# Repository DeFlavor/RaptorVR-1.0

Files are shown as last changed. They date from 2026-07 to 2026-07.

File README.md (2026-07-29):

# RaptorVR 1.0

RaptorVR 1.0 is a **prototype** SlimeVR carrier and enclosure for the **ELEGOO ESP-WROOM-32 USB-C 30-pin development board** and the **SlimeVR MuMo V1.1 ICM-45686 + QMC6309 breakout**. Its rounded outline, clear assembly zones, paired 1N5817 charge diodes, through-hole construction, and 50 mm strap chassis are inspired by the meowCarrier approach while using a larger ESP32-specific layout.

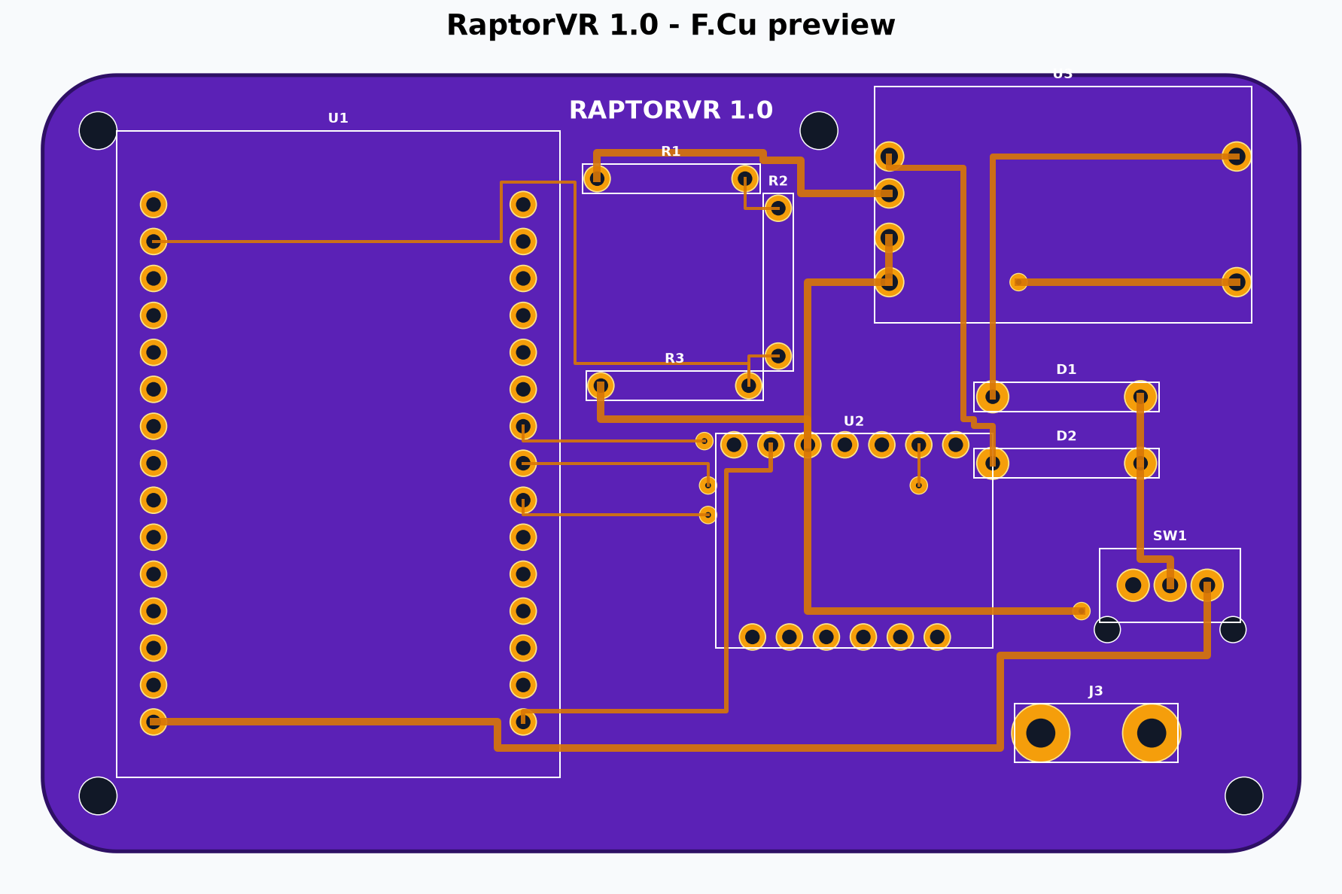
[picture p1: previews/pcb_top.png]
PCB preview


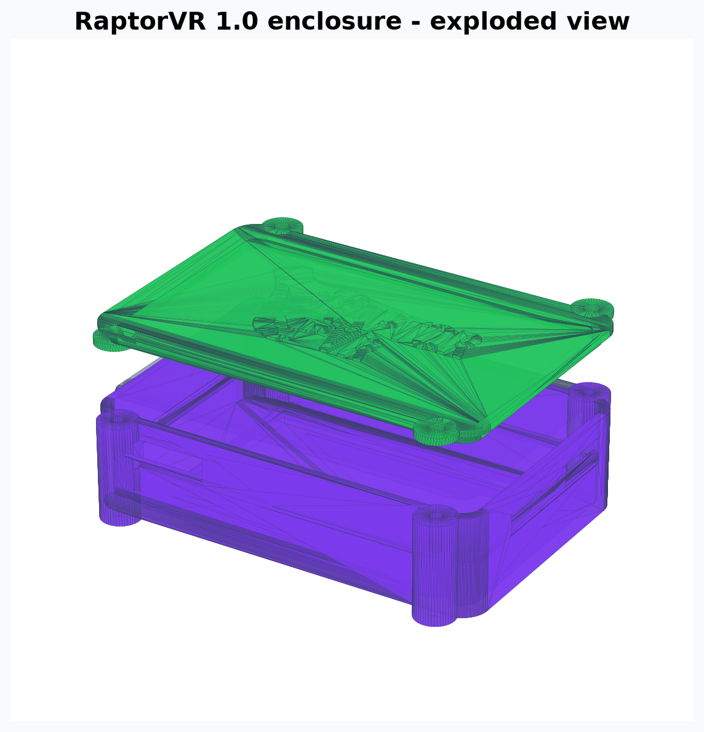
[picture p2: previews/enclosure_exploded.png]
Enclosure exploded view


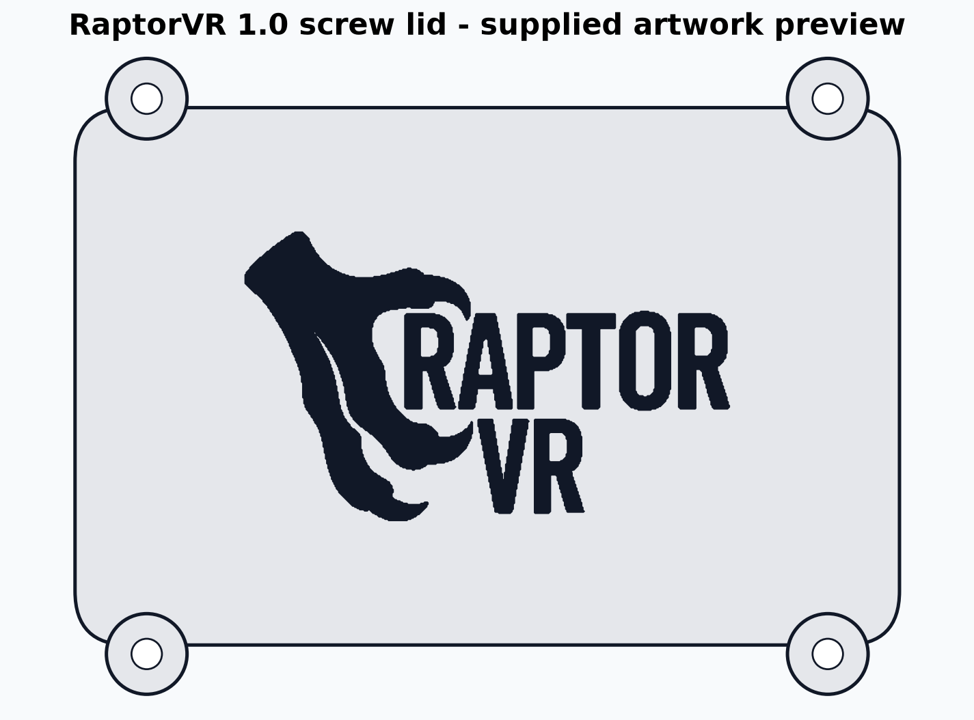
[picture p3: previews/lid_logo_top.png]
Raised logo lid preview


## Important status

This package passed automated geometry, copper-clearance, Gerber-parsing, and watertight-mesh checks. It has **not** been fabricated or electrically bench-tested. Treat revision 0.12 as a prototype and inspect it in a Gerber viewer before ordering.

## Supported parts

- ELEGOO ESP-WROOM-32 USB-C, 30 pins, two 15-pin rows on 2.54 mm pitch and 25.4 mm row spacing.
- MuMo V1.1, 18 x 13 mm, 1.2 mm thick, with both the seven-pin `J1 TOP_PINS` edge and six-pin `J2 BOTTOM_PINS` edge fitted.
- Protected TP4056 USB-C single-cell charger module, nominally 26 x 17 mm, with `IN+`, `IN-`, `B+`, `B-`, `OUT+`, and `OUT-` pads.
- Two axial 1N5817 Schottky diodes.
- 180 kOhm, 220 kOhm, and 100 kOhm 1/4 W resistors. The three-resistor divider matches the current SlimeVR `BOARD_WROOM32` defaults and feeds GPIO36/VP.
- SK12D07/SK12D07VG high-3mm SPDT slide switch.
- One protected 3.7 V, one-cell LiPo up to approximately 64 x 42 x 12 mm. The confirmed 1500 mAh battery measures 52 x 30.5 x 11 mm and fits with clearance.
- One adjustable 50 mm (2-inch) elastic or nylon body strap, 1.0-2.0 mm thick, with a side-release buckle or hook-and-loop adjustment.

## JLCPCB files

Upload [`hardware/pcb/RaptorVR_1_0_JLCPCB_Gerbers.zip`](hardware/pcb/RaptorVR_1_0_JLCPCB_Gerbers.zip) directly to JLCPCB. Recommended prototype settings:

- 2 layers, 86.36 x 53.34 mm
- 1.0 mm FR-4
- Purple solder mask for the shown style, or green for the quickest fabrication
- Lead-free HASL
- 1 oz copper
- Remove order number: specify the bottom `JLCJLCJLCJLC` location if the ordering interface supports it

The design is through-hole/module assembled. `BOM.csv` is a purchasing list; `CPL.csv` intentionally contains no SMT placement data.

## MuMo and firmware wiring

The PCB is SPI-first:

| Signal | ESP32 | MuMo |
| --- | --- | --- |
| SCLK | GPIO18 | J1.4 SCL |
| MOSI | GPIO23 | J1.5 SDA |
| MISO | GPIO19 | J1.7 SDO |
| CS | GPIO5 | J1.6 CS |
| INT1 | GPIO17 | J2.3 INT1 |
| Power | 3V3 | J1.2 3V3 |
| Ground | GND | J1.3 GND |

The same SCL/SDA wires can be used for I2C if the MuMo jumpers are configured according to its official instructions. For SPI, use a custom SlimeVR build with the pins above and ICM-45686 selected. Do not assume a generic prebuilt WROOM32 image has this exact custom SPI map.

Battery monitoring uses GPIO36/VP and these firmware values, in kOhm:

```cpp
#define PIN_BATTERY_LEVEL 36
#define BATTERY_SHIELD_RESISTANCE 180
#define BATTERY_SHIELD_R2 220
#define BATTERY_SHIELD_R1 100
```

## Enclosure

Creality Print can import the STL files in `hardware/enclosure/`:

- `RaptorVR_1_0_case_50mm_strap`: rounded chassis with ESP32 USB-C, charger USB-C, switch openings, four reinforced screw bosses, and two reinforced underside rails rotated so its 92 mm long side is vertical when worn with a 50 mm body strap.
- `RaptorVR_1_0_battery_separator_tray`: full insulating barrier between the LiPo and PCB, with PCB standoffs and a small wire slot.
- `RaptorVR_1_0_screw_lid_M3`: positively retained lid with four 3.4 mm M3 clearance holes, a 0.20 mm-per-side alignment plug, and the centered raised RaptorVR logo.
- `RaptorVR_1_0_chassis_assembled.glb` and `RaptorVR_1_0_chassis_exploded.glb`: accurate colored models for interactive orbit and zoom viewing.

The complete supplied logo image is traced directly into the lid—raptor mark, original lettering shapes, spacing, and the original `RAPTOR`/`VR` two-line arrangement. No substitute font is used. The artwork is scaled uniformly to 54 mm wide and embossed 0.8 mm above the lid for clear resin and FDM visibility. For a contrasting FDM logo, add a filament change for the final four 0.20 mm layers; a single-color print also works. For resin, angle the lid approximately 20-30 degrees and place supports on the inside face so the raised logo remains clean.

Use four **M3 x 10 mm thread-forming/self-tapping pan-head screws for plastic**. The case has 2.6 mm blind pilot holes, so the screw tips cannot reach the PCB or battery. Tighten only until the lid is seated; overtightening can strip printed threads. Do not use screws longer than 10 mm unless you first verify the remaining boss depth.

For vertical body mounting, thread one **50 mm (2-inch) elastic or nylon strap** beneath both underside rails, then add an adjustable side-release buckle or hook-and-loop closure. The rails are turned 90 degrees from the earlier layout: the strap travels across the 60 mm short side, leaving the 92 mm long side vertical on your body. The passages are 50.5 mm wide and 2.2 mm high. Round or lightly sand any sharp printed edges before installing the strap, leave enough slack for comfortable movement and circulation, and inspect the strap and rails before each use. Do not resin-print the flexible strap itself.

Starting Creality settings: 0.4 mm nozzle, 0.20 mm layers, four walls, five top/bottom layers, 35% gyroid infill, PLA+ or PETG. Print the case upright, the separator flat, and the lid with its large outer face on the build plate. If your printer runs tight, scale only the lid X/Y to 100.2% or lightly sand the alignment plug.

## Assembly safety

1. Do not attach the LiPo until every other part is soldered and inspected.
2. Verify `BAT+` and `BAT-` with a multimeter. Reversed LiPo polarity can cause fire.
3. Use only a protected one-cell LiPo and a TP4056 board that includes battery protection.
4. Confirm the TP4056 pad order against its seller diagram; visually similar boards can differ.
5. Check for shorts from `SYS_5V` to ground and from `3V3` to ground before inserting the ESP32 or MuMo.
6. The striped end of each 1N5817 goes to the PCB pad marked `K`.
7. Use USB-A-to-USB-C for inexpensive TP4056 modules unless the module explicitly supports USB-C-to-C charging.
8. Never charge an unattended or damaged LiPo, and do not wear the tracker while charging.

## Source and regeneration

- Editable PCB layout: `hardware/pcb/source/RaptorVR_1_0.kicad_pcb`
- Dimension-controlled generator: `hardware/pcb/source/generate_project.py`
- Supplied logo reference: `hardware/pcb/source/assets/RaptorVR_logo_reference.png`
- Human-readable schematic: `hardware/pcb/schematic/RaptorVR_1_0_schematic.pdf`
- Validation report: `VALIDATION.json`

Regenerate with Python 3.12 plus `numpy`, `Pillow`, `shapely`, `trimesh`, `manifold3d`, `matplotlib`, `reportlab`, and `gerbonara`.

## References and attribution

- meowCarrier by Shine Bright (MIT): https://github.com/Shine-Bright-Meow/meowCarrier
- SlimeVR tracker documentation: https://docs.slimevr.dev/diy/tracker-schematics.html
- Official MuMo V1.1 schematic: https://docs.slimevr.dev/files/mumo-schematic-1.1.pdf
- SlimeVR firmware: https://github.com/SlimeVR/SlimeVR-Tracker-ESP

The RaptorVR 1.0 scripts, PCB layout, documentation, and enclosure geometry are released under the MIT License. Third-party modules and reference projects retain their original licenses.

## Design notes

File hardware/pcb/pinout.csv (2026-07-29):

Function | ESP32 pin | MuMo pin | Notes
SPI SCLK / I2C SCL | GPIO18 | J1.4 SCL | 24 MHz SPI preferred; same wire can be I2C SCL
SPI MOSI / I2C SDA | GPIO23 | J1.5 SDA | Same wire can be I2C SDA
SPI MISO | GPIO19 | J1.7 SDO | Used in SPI mode
SPI CS | GPIO5 | J1.6 CS | Used in SPI mode
Interrupt | GPIO17 | J2.3 INT1 | Custom firmware pin
Battery ADC | GPIO36 / VP | - | 180k + 220k over 100k divider
Module power | 3V3 | J1.2 3V3 | Do not power MuMo from 5V
Ground | GND | J1.3 GND | Common ground

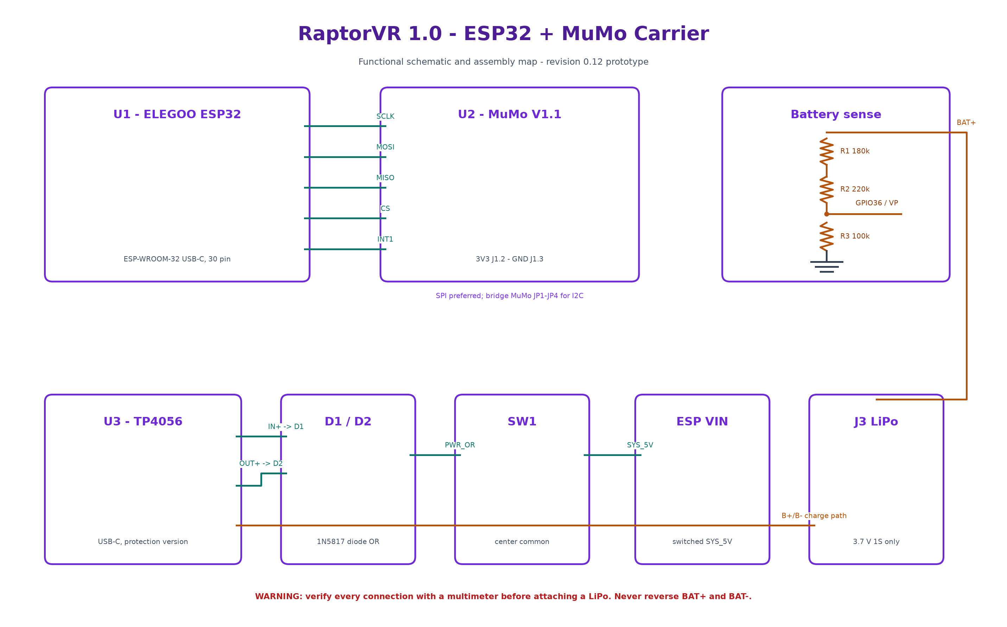
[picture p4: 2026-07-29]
hardware/pcb/schematic/RaptorVR_1_0_schematic.png

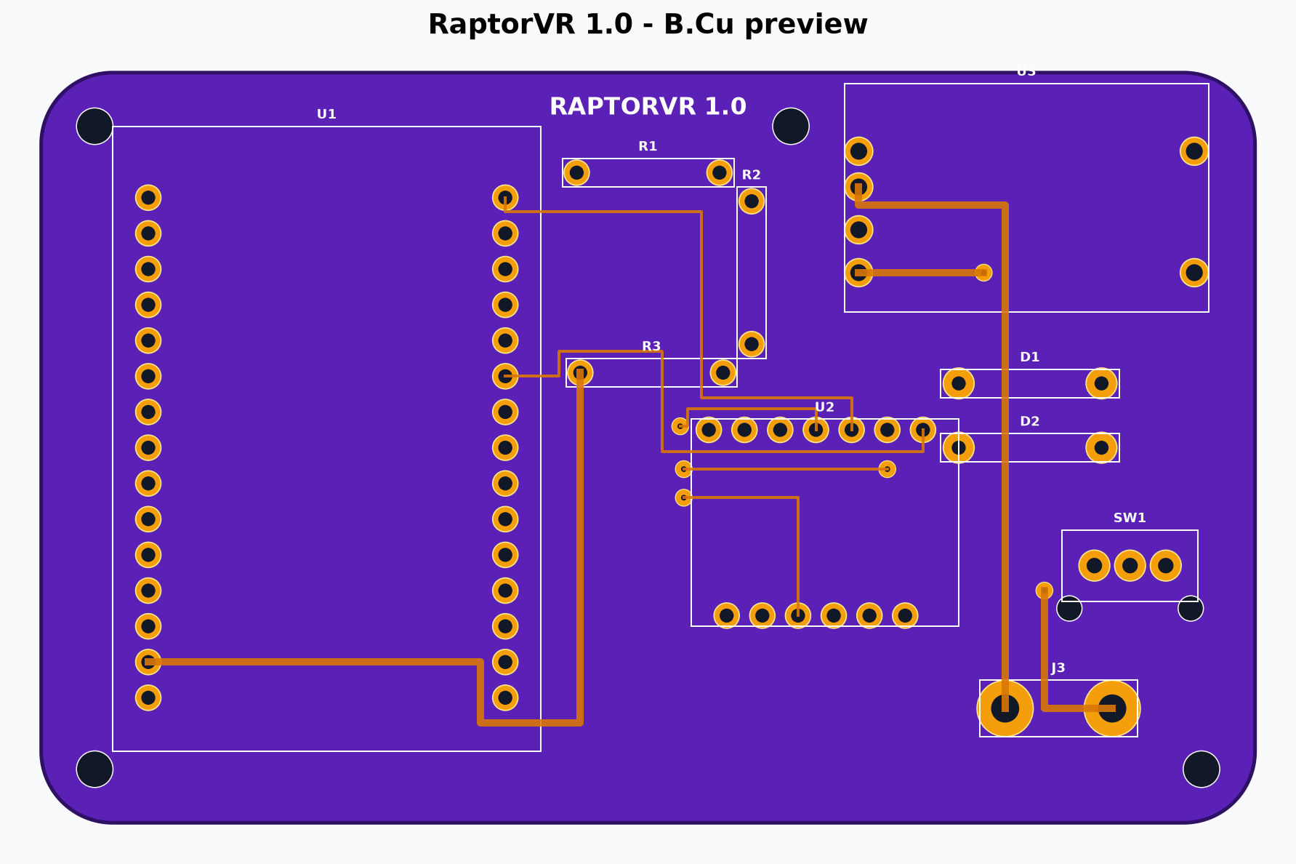
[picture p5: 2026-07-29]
previews/pcb_bottom.png

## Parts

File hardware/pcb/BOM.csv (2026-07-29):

Reference | Qty | Value / Part | Footprint / Notes | Assembly
U1 | 1 | ELEGOO ESP-WROOM-32 USB-C 30-pin | 2x15, 2.54 mm pitch, 25.4 mm row spacing | Socket or solder headers
U2 | 1 | SlimeVR MuMo V1.1 ICM-45686 + QMC6309 | 18 x 13 mm, 7+6 castellated/header pins | Fit both rows for SPI
U3 | 1 | Protected TP4056 USB-C module | Approx. 26 x 17 mm; IN+/IN-/B+/B-/OUT+/OUT- | Protection version required
D1,D2 | 2 | 1N5817 Schottky diode | DO-41 axial, 10.16 mm pitch | Band/cathode toward K
R1 | 1 | 180 kOhm 1/4 W | Axial, 10.16 mm pitch | Battery sense
R2 | 1 | 220 kOhm 1/4 W | Axial, 10.16 mm pitch | Battery divider upper
R3 | 1 | 100 kOhm 1/4 W | Axial, 10.16 mm pitch | Battery divider lower
SW1 | 1 | SK12D07/SK12D07VG high-3mm | SPDT, 2.54 mm pin pitch | Center common
J3 | 1 | 503759 3.7 V protected LiPo | Bare red/black leads to large pads | Verify polarity before soldering
Headers | 1 | 2.54 mm male/female header assortment | For ESP32, MuMo, TP4056 | Trim flush under PCB
STRAP | 1 | 50 mm (2-inch) adjustable elastic or nylon body strap with buckle | 1.0-2.0 mm thick webbing; choose a length for the intended body location | Thread beneath both rails so the chassis long side is vertical

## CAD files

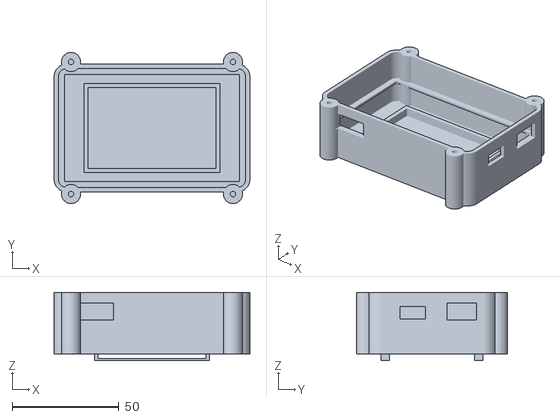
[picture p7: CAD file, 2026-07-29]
hardware/enclosure/RaptorVR_1_0_case_50mm_strap.stl
92.0 x 71.0 x 32.0

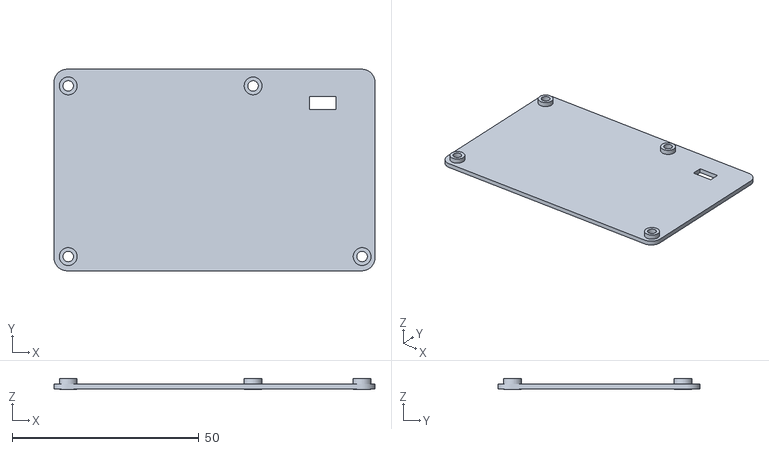
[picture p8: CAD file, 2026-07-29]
hardware/enclosure/RaptorVR_1_0_battery_separator_tray.stl
86.0 x 54.0 x 3.00

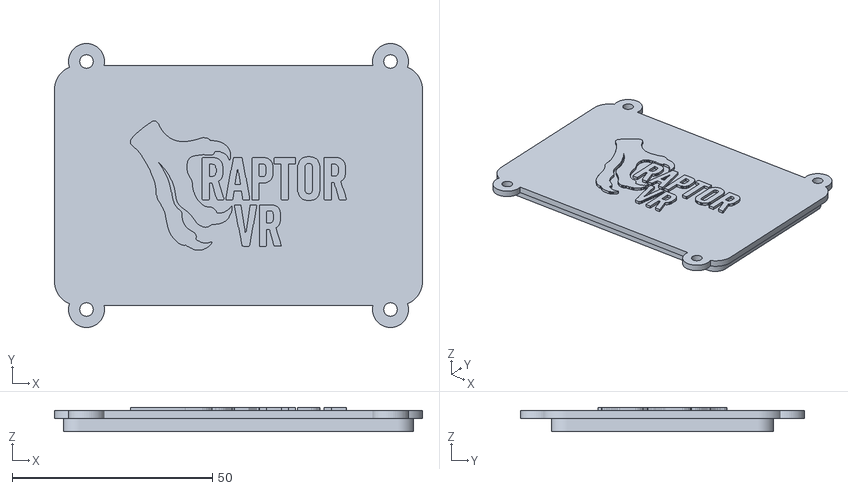
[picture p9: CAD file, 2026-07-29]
hardware/enclosure/RaptorVR_1_0_screw_lid_M3.stl
92.0 x 71.0 x 6.00

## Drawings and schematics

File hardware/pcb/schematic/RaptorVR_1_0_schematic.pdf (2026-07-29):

## U1 - ELEGOO ESP32

## U2 - MuMo V1.1

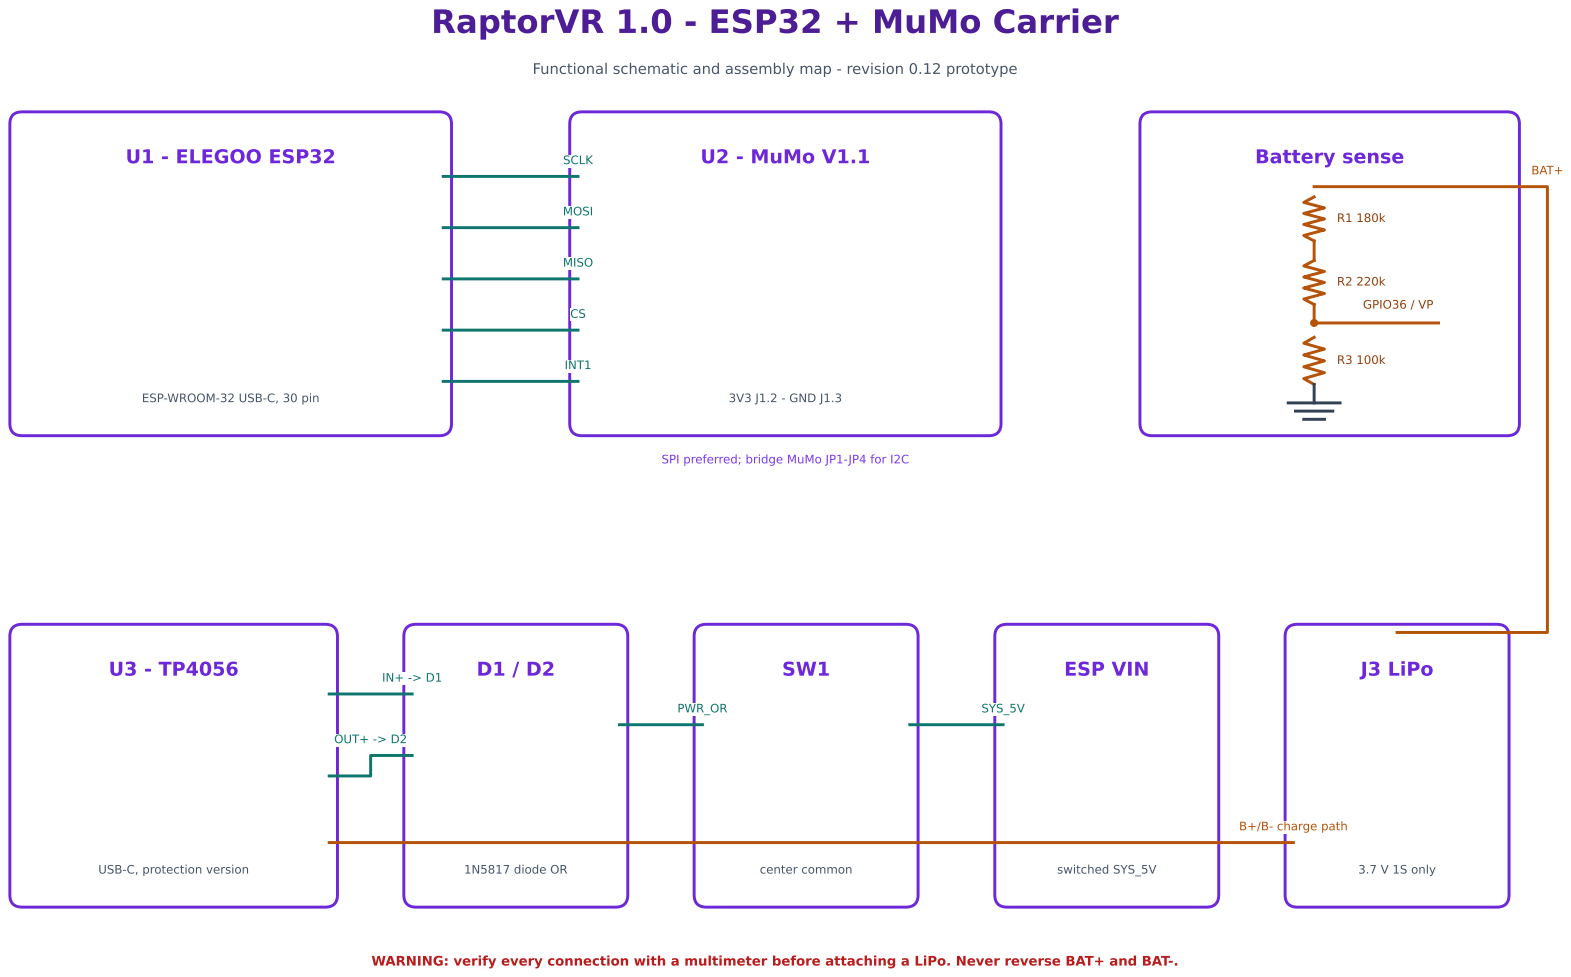
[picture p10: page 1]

Functional schematic and assembly map - revision 0.12 prototype

ESP-WROOM-32 USB-C, 30 pin

SPI preferred; bridge MuMo JP1-JP4 for I2C

WARNING: verify every connection with a multimeter before attaching a LiPo. Never reverse BAT+ and BAT-.

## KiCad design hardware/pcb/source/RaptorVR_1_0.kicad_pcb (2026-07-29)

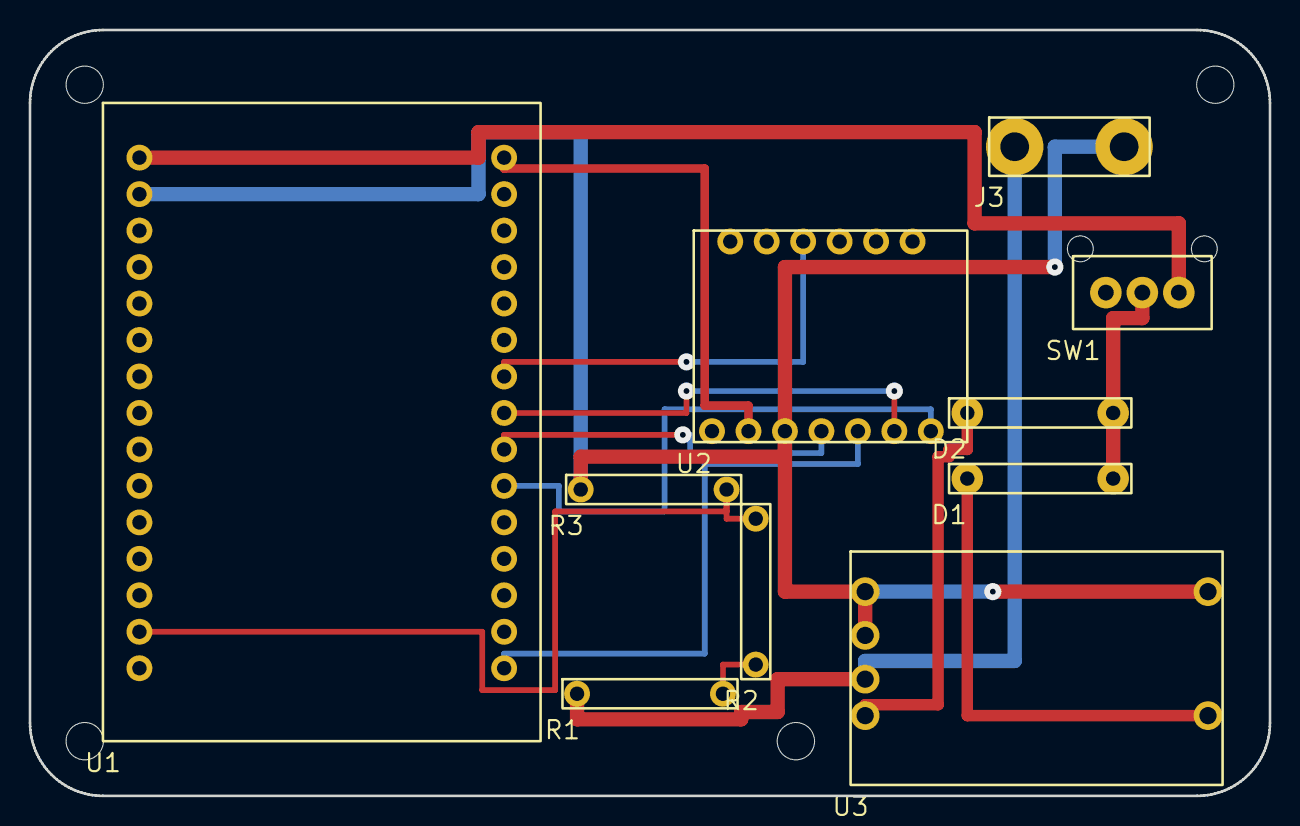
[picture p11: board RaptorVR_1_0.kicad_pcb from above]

Board: 2 copper layers, 86.4 x 53.3 mm, 10 parts (0 on the bottom side), 14 nets.

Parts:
D1: 1N5817; D1
D2: 1N5817; D2
J3: LiPo wire pads; J3
R1: 180k 1/4W; R1
R2: 220k 1/4W; R2
R3: 100k 1/4W; R3
SW1: SK12D07VG3 high-3mm; SW1
U1: ELEGOO ESP-WROOM-32 USB-C 30-pin; U1
U2: MuMo V1.1 ICM-45686 + QMC6309; U2
U3: TP4056 USB-C protected module; U3

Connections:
3V3: U1.R1, U2.2
ADC_BAT: R2.2, R3.2, U1.L14
BAT+: J3.+, R1.1, U3.5
CHG_OUT: D2.1, U3.6
CS: U1.R8, U2.6
DIV_A: R1.2, R2.1
GND: J3.-, R3.1, U1.L2, U2.3, U3.2, U3.4, U3.7
INT1: U1.R7, U2.3
MISO: U1.R10, U2.7
MOSI: U1.R15, U2.5
PWR_OR: D1.2, D2.2, SW1.2
SCLK: U1.R9, U2.4
SYS_5V: SW1.3, U1.L1
USB_IN: D1.1, U3.1

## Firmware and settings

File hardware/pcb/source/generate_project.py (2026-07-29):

from __future__ import annotations

import csv
import heapq
import io
import json
import math
import shutil
import textwrap
import zipfile
from collections import defaultdict
from dataclasses import dataclass, field
from pathlib import Path

import matplotlib

matplotlib.use("Agg")
import matplotlib.pyplot as plt
from matplotlib.patches import Circle, FancyBboxPatch, Rectangle
from matplotlib.path import Path as MplPath
from matplotlib.textpath import TextPath
from matplotlib.transforms import Affine2D
from mpl_toolkits.mplot3d.art3d import Poly3DCollection
import numpy as np
import trimesh
from PIL import Image
from shapely.affinity import scale as scale_geometry
from shapely.affinity import translate as translate_geometry
from shapely.geometry import LineString, Point, Polygon, box
from shapely.ops import unary_union


SCRIPT_PATH = Path(__file__).resolve()
SCRIPT_BYTES = SCRIPT_PATH.read_bytes()
ROOT = next(
    (
        candidate
        for candidate in SCRIPT_PATH.parents
        if (candidate / "work").is_dir() and (candidate / "outputs").is_dir()
    ),
    SCRIPT_PATH.parents[1],
)
OUT = ROOT / "outputs" / "esp32-mumo-tracker"
PCB = OUT / "hardware" / "pcb"
GERBERS = PCB / "gerbers"
SCHEMATIC = PCB / "schematic"
SOURCE = PCB / "source"
PRINTABLES = OUT / "hardware" / "enclosure"
PREVIEWS = OUT / "previews"
LOGO_ASSET = Path(__file__).resolve().parent / "assets" / "RaptorVR_logo_reference.png"
LOGO_PNG_BYTES = LOGO_ASSET.read_bytes()

GRID = 0.254  # 10 mil routing grid
BOARD_W = 86.36
BOARD_H = 53.34
BOARD_R = 5.08
CLEARANCE = 0.250
ROUTER_MARGIN = 0.18  # absorbs 10 mil grid quantization so exact geometry still clears 0.25 mm


@dataclass
class Pad:
    ref: str
    pin: str
    x: float
    y: float
    net: str
    diameter: float = 1.80
    drill: float = 1.00
    plated: bool = True
    label: str = ""

    @property
    def key(self):
        return f"{self.ref}.{self.pin}"


@dataclass
class Component:
    ref: str
    value: str
    description: str
    outline: tuple[float, float, float, float]
    pads: list[Pad] = field(default_factory=list)


@dataclass
class Track:
    net: str
    layer: str
    points: list[tuple[float, float]]
    width: float


@dataclass
class Via:
    net: str
    x: float
    y: float
    diameter: float = 1.20
    drill: float = 0.40


def mm(v: int) -> float:
    return round(v * GRID, 6)


def rounded_rect_polygon(w: float, h: float, r: float, inset: float = 0.0) -> Polygon:
    return unary_union([
        box(inset + r, inset, w - inset - r, h - inset),
        box(inset, inset + r, w - inset, h - inset - r),
        Point(inset + r, inset + r).buffer(r, resolution=32),
        Point(w - inset - r, inset + r).buffer(r, resolution=32),
        Point(w - inset - r, h - inset - r).buffer(r, resolution=32),
        Point(inset + r, h - inset - r).buffer(r, resolution=32),
    ])


def build_components() -> tuple[list[Component], list[Pad], list[Pad]]:
    components: list[Component] = []
    pads: list[Pad] = []
    npth: list[Pad] = []

    # ELEGOO ESP-WROOM-32 USB-C 30-pin board. USB-C faces the lower board edge.
    left_names = [
        ("VIN", "SYS_5V"), ("GND", "GND"), ("GPIO13", "NC"), ("GPIO12", "NC"),
        ("GPIO14", "NC"), ("GPIO27", "NC"), ("GPIO26", "NC"), ("GPIO25", "NC"),
        ("GPIO33", "NC"), ("GPIO32", "NC"), ("GPIO35", "NC"), ("GPIO34", "NC"),
        ("GPIO39", "NC"), ("GPIO36", "ADC_BAT"), ("EN", "NC"),
    ]
    right_names = [
        ("3V3", "3V3"), ("GPIO15", "NC"), ("GPIO2", "NC"), ("GPIO0", "NC"),
        ("GPIO4", "NC"), ("GPIO16", "NC"), ("GPIO17", "INT1"), ("GPIO5", "CS"),
        ("GPIO18", "SCLK"), ("GPIO19", "MISO"), ("GPIO21", "NC"), ("RX0", "NC"),
        ("TX0", "NC"), ("GPIO22", "NC"), ("GPIO23", "MOSI"),
    ]
    esp_pads = []
    for side, x, names in [("L", mm(30), left_names), ("R", mm(130), right_names)]:
        for i, (label, net) in enumerate(names):
            p = Pad("U1", f"{side}{i+1}", x, mm(35 + i * 10), net, label=label)
            esp_pads.append(p)
    components.append(Component("U1", "ELEGOO ESP-WROOM-32 USB-C 30-pin", "30-pin ESP32 development board", (mm(20), mm(20), mm(140), mm(195)), esp_pads))
    pads.extend(esp_pads)

    # MuMo V1.1 footprint: 7 top pins and 6 bottom pins, centered on an 18 x 13 mm board.
    j1_signals = [
        ("OSDO", "NC"), ("3V3", "3V3"), ("GND", "GND"), ("SCL/SCK", "SCLK"),
        ("SDA/MOSI", "MOSI"), ("CS", "CS"), ("SDO/MISO", "MISO"),
    ]
    j2_signals = [
        ("OCS", "NC"), ("CLK", "NC"), ("INT1", "INT1"), ("SCX", "NC"),
        ("SDX", "NC"), ("CLK_CTL", "NC"),
    ]
    mumo_pads = []
    for i, (label, net) in enumerate(j1_signals):
        mumo_pads.append(Pad("J1", str(i + 1), mm(187 + i * 10), mm(110), net, label=label))
    for i, (label, net) in enumerate(j2_signals):
        mumo_pads.append(Pad("J2", str(i + 1), mm(192 + i * 10), mm(58), net, label=label))
    components.append(Component("U2", "MuMo V1.1 ICM-45686 + QMC6309", "13 x 18 mm dual-row castellated breakout", (mm(182), mm(55), mm(257), mm(113)), mumo_pads))
    pads.extend(mumo_pads)

    # Common protected TP4056 USB-C module (about 26 x 17 mm). USB-C faces right.
    tp = [
        Pad("U3", "1", mm(323), mm(188), "USB_IN", 2.00, 1.20, label="IN+"),
        Pad("U3", "2", mm(323), mm(154), "GND", 2.00, 1.20, label="IN-"),
        Pad("U3", "4", mm(229), mm(166), "GND", 2.00, 1.20, label="B-"),
        Pad("U3", "5", mm(229), mm(178), "BAT+", 2.00, 1.20, label="B+"),
        Pad("U3", "6", mm(229), mm(188), "CHG_OUT", 2.00, 1.20, label="OUT+"),
        Pad("U3", "7", mm(229), mm(154), "GND", 2.00, 1.20, label="OUT-"),
    ]
    components.append(Component("U3", "TP4056 USB-C protected module", "6-pad single-cell Li-ion charger/protection module", (mm(225), mm(143), mm(327), mm(207)), tp))
    pads.extend(tp)

    # Axial 1N5817 diodes, cathodes toward the power-OR node.
    d1 = [Pad("D1", "1", mm(257), mm(123), "USB_IN", 2.20, 1.00, label="A"), Pad("D1", "2", mm(297), mm(123), "PWR_OR", 2.20, 1.00, label="K")]
    d2 = [Pad("D2", "1", mm(257), mm(105), "CHG_OUT", 2.20, 1.00, label="A"), Pad("D2", "2", mm(297), mm(105), "PWR_OR", 2.20, 1.00, label="K")]
    components.extend([
        Component("D1", "1N5817", "USB-to-load Schottky diode", (mm(252), mm(119), mm(302), mm(127)), d1),
        Component("D2", "1N5817", "battery-to-load Schottky diode", (mm(252), mm(101), mm(302), mm(109)), d2),
    ])
    pads.extend(d1 + d2)

    # Battery divider matching SlimeVR BOARD_WROOM32 defaults: 180k + 220k over 100k.
    r180 = [Pad("R1", "1", mm(150), mm(182), "BAT+", label="BAT+"), Pad("R1", "2", mm(190), mm(182), "DIV_A", label="DIV_A")]
    r220 = [Pad("R2", "1", mm(199), mm(174), "DIV_A", label="DIV_A"), Pad("R2", "2", mm(199), mm(134), "ADC_BAT", label="ADC")]
    r100 = [Pad("R3", "1", mm(151), mm(126), "GND", label="GND"), Pad("R3", "2", mm(191), mm(126), "ADC_BAT", label="ADC")]
    components.extend([
        Component("R1", "180k 1/4W", "battery sense series resistor", (mm(146), mm(178), mm(194), mm(186)), r180),
        Component("R2", "220k 1/4W", "battery sense upper divider resistor", (mm(195), mm(130), mm(203), mm(178)), r220),
        Component("R3", "100k 1/4W", "battery sense lower divider resistor", (mm(147), mm(122), mm(195), mm(130)), r100),
    ])
    pads.extend(r180 + r220 + r100)

    # SK12D07/SK12D07VG. Center common, right pad ON; left pad unused/OFF.
    sw = [
        Pad("SW1", "1", mm(295), mm(72), "NC", 2.20, 1.10, label="OFF"),
        Pad("SW1", "2", mm(305), mm(72), "PWR_OR", 2.20, 1.10, label="COM"),
        Pad("SW1", "3", mm(315), mm(72), "SYS_5V", 2.20, 1.10, label="ON"),
    ]
    components.append(Component("SW1", "SK12D07VG3 high-3mm", "SPDT slide power switch", (mm(286), mm(62), mm(324), mm(82)), sw))
    pads.extend(sw)
    npth.extend([
        Pad("SW1", "M1", mm(288), mm(60), "NPTH", 1.80, 1.80, False),
        Pad("SW1", "M2", mm(322), mm(60), "NPTH", 1.80, 1.80, False),
    ])

    # Large wire pads for the single-cell LiPo.
    bat = [
        Pad("J3", "+", mm(270), mm(32), "BAT+", 4.00, 2.00, label="BAT+"),
        Pad("J3", "-", mm(300), mm(32), "GND", 4.00, 2.00, label="BAT-")
    ]
    components.append(Component("J3", "LiPo wire pads", "3.7 V single-cell battery connection", (mm(263), mm(24), mm(307), mm(40)), bat))
    pads.extend(bat)

    # Mounting holes matching the separator tray standoffs.
    for i, (x, y) in enumerate([(mm(15), mm(15)), (mm(325), mm(15)), (mm(15), mm(195)), (mm(210), mm(195))], 1):
        npth.append(Pad("H", str(i), x, y, "NPTH", 3.00, 2.60, False))

    return components, pads, npth


def prim_edges(items: list[Pad]) -> list[tuple[Pad, Pad]]:
    if len(items) < 2:
        return []
    used = {0}
    edges = []
    while len(used) < len(items):
        best = None
        for i in used:
            for j in range(len(items)):
                if j in used:
                    continue
                d = (items[i].x - items[j].x) ** 2 + (items[i].y - items[j].y) ** 2
                if best is None or d < best[0]:
                    best = (d, i, j)
        assert best
        _, i, j = best
        edges.append((items[i], items[j]))
        used.add(j)
    return edges


class Router:
    def __init__(self, pads: list[Pad], npth: list[Pad]):
        self.pads = pads
        self.npth = npth
        self.nx = round(BOARD_W / GRID)
        self.ny = round(BOARD_H / GRID)
        self.occ = [defaultdict(set), defaultdict(set)]  # cell -> nets occupying expanded copper
        self.hard = [set(), set()]
        self.vias: list[Via] = []
        self.tracks: list[Track] = []
        self.board_safe = rounded_rect_polygon(BOARD_W, BOARD_H, BOARD_R).buffer(-0.55)
        self._mark_pad_obstacles()

    def _grid_xy(self, x: float, y: float) -> tuple[int, int]:
        return round(x / GRID), round(y / GRID)

    def _in_board(self, ix: int, iy: int) -> bool:
        if ix < 1 or iy < 1 or ix >= self.nx or iy >= self.ny:
            return False
        return self.board_safe.contains(Point(ix * GRID, iy * GRID))

    def _mark_disc(self, ix: int, iy: int, radius_mm: float, target, value):
        rr = math.ceil(radius_mm / GRID)
        for dx in range(-rr, rr + 1):
            for dy in range(-rr, rr + 1):
                if (dx * GRID) ** 2 + (dy * GRID) ** 2 <= radius_mm ** 2:
                    target[(ix + dx, iy + dy)].add(value) if isinstance(target, defaultdict) else target.add((ix + dx, iy + dy))

    def _mark_pad_obstacles(self):
        for p in self.pads:
            if p.net == "NC":
                net = p.key
            else:
                net = p.net
            ix, iy = self._grid_xy(p.x, p.y)
            for layer in range(2):
                self._mark_disc(ix, iy, p.diameter / 2 + CLEARANCE + ROUTER_MARGIN, self.occ[layer], net)
        for p in self.npth:
            ix, iy = self._grid_xy(p.x, p.y)
            for layer in range(2):
                self._mark_disc(ix, iy, p.drill / 2 + 0.60, self.hard[layer], "HARD")

    def _cell_ok(self, ix: int, iy: int, layer: int, net: str, width: float = 0.40, via: bool = False) -> bool:
        if not self._in_board(ix, iy):
            return False
        radius = 0.60 if via else width / 2
        rr = math.ceil(radius / GRID)
        layers = (0, 1) if via else (layer,)
        for ll in layers:
            for dx in range(-rr, rr + 1):
                for dy in range(-rr, rr + 1):
                    if (dx * GRID) ** 2 + (dy * GRID) ** 2 > radius ** 2:
                        continue
                    cell = (ix + dx, iy + dy)
                    if cell in self.hard[ll]:
                        return False
                    values = self.occ[ll].get(cell, set())
                    if values and any(v != net for v in values):
                        return False
        return True

    def _astar(self, a: Pad, b: Pad, net: str, width: float) -> list[tuple[int, int, int]]:
        sx, sy = self._grid_xy(a.x, a.y)
        gx, gy = self._grid_xy(b.x, b.y)
        starts = [(sx, sy, 0), (sx, sy, 1)]
        goals = {(gx, gy, 0), (gx, gy, 1)}
        pq = []
        prev = {}
        gscore = {}
        for s in starts:
            gscore[s] = 0.0
            heapq.heappush(pq, (abs(sx - gx) + abs(sy - gy), 0.0, s, None))
        visited = set()
        max_iter = self.nx * self.ny * 3
        iters = 0
        while pq and iters < max_iter:
            _, cost, state, direction = heapq.heappop(pq)
            iters += 1
            if state in visited:
                continue
            visited.add(state)
            if state in goals:
                path = [state]
                while state in prev:
                    state = prev[state]
                    path.append(state)
                return list(reversed(path))
            x, y, layer = state
            for dx, dy, ndir in ((1, 0, 0), (-1, 0, 0), (0, 1, 1), (0, -1, 1)):
                nx, ny = x + dx, y + dy
                ns = (nx, ny, layer)
                if not self._cell_ok(nx, ny, layer, net, width=width):
                    continue
                turn = 0.18 if direction is not None and ndir != direction else 0.0
                nc = cost + 1.0 + turn
                if nc < gscore.get(ns, 1e30):
                    gscore[ns] = nc
                    prev[ns] = state
                    h = abs(nx - gx) + abs(ny - gy)
                    heapq.heappush(pq, (nc + h, nc, ns, ndir))
            other = 1 - layer
            ns = (x, y, other)
            if self._cell_ok(x, y, layer, net, width=width, via=True):
                nc = cost + 14.0
                if nc < gscore.get(ns, 1e30):
                    gscore[ns] = nc
                    prev[ns] = state
                    h = abs(x - gx) + abs(y - gy)
                    heapq.heappush(pq, (nc + h, nc, ns, direction))
        raise RuntimeError(f"Autorouter failed for {net}: {a.key} -> {b.key}")

    def _commit(self, path: list[tuple[int, int, int]], net: str, width: float):
        # Mark copper occupancy with clearance.
        route_radius = width / 2 + CLEARANCE + ROUTER_MARGIN
        rr = math.ceil(route_radius / GRID)
        for x, y, layer in path:
            for dx in range(-rr, rr + 1):
                for dy in range(-rr, rr + 1):
                    if (dx * GRID) ** 2 + (dy * GRID) ** 2 <= route_radius ** 2:
                        self.occ[layer][(x + dx, y + dy)].add(net)

        # Split by layer and compress collinear grid walks.
        chunks = []
        chunk = [path[0]]
        for item in path[1:]:
            if item[2] != chunk[-1][2]:
                chunks.append(chunk)
                chunk = [item]
            else:
                chunk.append(item)
        chunks.append(chunk)
        for ch in chunks:
            if len(ch) < 2:
                continue
            pts = [(ch[0][0], ch[0][1])]
            last_dir = None
            for i in range(1, len(ch)):
                d = (ch[i][0] - ch[i - 1][0], ch[i][1] - ch[i - 1][1])
                if last_dir is not None and d != last_dir:
                    pts.append((ch[i - 1][0], ch[i - 1][1]))
                last_dir = d
            pts.append((ch[-1][0], ch[-1][1]))
            mmpts = [(mm(x), mm(y)) for x, y in pts]
            self.tracks.append(Track(net, "F.Cu" if ch[0][2] == 0 else "B.Cu", mmpts, width))

        for i in range(1, len(path)):
            if path[i][2] != path[i - 1][2]:
                x, y, _ = path[i]
                if not any(abs(v.x - mm(x)) < 1e-6 and abs(v.y - mm(y)) < 1e-6 and v.net == net for v in self.vias):
                    via = Via(net, mm(x), mm(y))
                    self.vias.append(via)
                    for ll in (0, 1):
                        self._mark_disc(x, y, via.diameter / 2 + CLEARANCE + ROUTER_MARGIN, self.occ[ll], net)

    def route_all(self):
        net_pads: dict[str, list[Pad]] = defaultdict(list)
        for p in self.pads:
            if p.net not in ("NC", "NPTH"):
                net_pads[p.net].append(p)

        order = [
            "USB_IN", "CHG_OUT", "PWR_OR", "SYS_5V", "BAT+", "3V3", "GND",
            "SCLK", "MOSI", "MISO", "CS", "INT1", "ADC_BAT", "DIV_A",
        ]
        widths = defaultdict(lambda: 0.40, {"USB_IN": 0.80, "CHG_OUT": 0.80, "PWR_OR": 1.00, "SYS_5V": 1.00, "BAT+": 1.00, "GND": 1.00, "3V3": 0.60})
        for net in order:
            items = net_pads[net]
            for a, b in prim_edges(items):
                path = self._astar(a, b, net, widths[net])
                self._commit(path, net, widths[net])
        return self.tracks, self.vias


def gerber_coord(v: float) -> str:
    return f"{round(v * 1_000_000):010d}"


def gerber_header(name: str) -> list[str]:
    return [
        f"G04 {name}*", "%FSLAX46Y46*%", "%MOMM*%", "%IPPOS*%", "%LPD*%",
        "%ADD10C,0.400*%", "%ADD11C,0.600*%", "%ADD12C,0.800*%", "%ADD13C,1.000*%",
        "%ADD14C,1.200*%", "%ADD15C,1.800*%", "%ADD16C,2.200*%", "%ADD17C,2.400*%",
        "%ADD18C,4.000*%", "%ADD19C,0.180*%", "G01*",
    ]


def flash(lines, x, y, dcode):
    lines.append(f"D{dcode}*")
    lines.append(f"X{gerber_coord(x)}Y{gerber_coord(y)}D03*")


def draw_polyline(lines, points, dcode):
    if len(points) < 2:
        return
    lines.append(f"D{dcode}*")
    x, y = points[0]
    lines.append(f"X{gerber_coord(x)}Y{gerber_coord(y)}D02*")
    for x, y in points[1:]:
        lines.append(f"X{gerber_coord(x)}Y{gerber_coord(y)}D01*")


def write_region(lines, poly: list[tuple[float, float]]):
    if len(poly) < 3:
        return
    lines.append("G36*")
    lines.append(f"X{gerber_coord(poly[0][0])}Y{gerber_coord(poly[0][1])}D02*")
    for x, y in poly[1:]:
        lines.append(f"X{gerber_coord(x)}Y{gerber_coord(y)}D01*")
    lines.append(f"X{gerber_coord(poly[0][0])}Y{gerber_coord(poly[0][1])}D01*")
    lines.append("G37*")


def text_polygons(text: str, x: float, y: float, size: float, angle: float = 0.0, center: bool = False):
    path = TextPath((0, 0), text, size=size, prop={"family": "DejaVu Sans", "weight": "bold"})
    polys = path.to_polygons()
    if not polys:
        return []
    allpts = np.vstack(polys)
    minx, miny = allpts.min(axis=0)
    maxx, maxy = allpts.max(axis=0)
    tx = -(minx + maxx) / 2 if center else -minx
    ty = -(miny + maxy) / 2 if center else -miny
    transform = Affine2D().translate(tx, ty).rotate_deg(angle).translate(x, y)
    return [transform.transform(p).tolist() for p in polys]
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

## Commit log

2026-07-29 Initial PurrTrack32 prototype design
    [BOM.csv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]
2026-07-29 Replace snap lid with four-screw M3 enclosure
    [PurrTrack32_case_50mm_strap.stl, PurrTrack32_screw_lid_M3.stl, PurrTrack32_snap_lid.stl]
2026-07-29 Rename project to RaptorVR 1.0
    [RaptorVR_1_0-B_Cu.gbl, RaptorVR_1_0-B_Mask.gbs, RaptorVR_1_0-B_Silkscreen.gbo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]
2026-07-29 Resize enclosure for 1500 mAh battery
    [RaptorVR_1_0_case_50mm_strap.stl]
2026-07-29 Add raised RaptorVR logo to screw lid
    [RaptorVR_1_0_screw_lid_M3.stl]
2026-07-29 Position lid lettering inside raptor grip
    [RaptorVR_1_0_screw_lid_M3.stl]
2026-07-29 Reduce lid logo lettering size
    [RaptorVR_1_0_screw_lid_M3.stl]
2026-07-29 Set RaptorVR lid text on one line
    [RaptorVR_1_0_screw_lid_M3.stl]
2026-07-29 Remove space from RaptorVR lid text
    [RaptorVR_1_0_screw_lid_M3.stl]
2026-07-29 Increase lid logo relief for resin printing
    [RaptorVR_1_0_screw_lid_M3.stl]
2026-07-29 Trace exact supplied logo artwork onto lid
    [RaptorVR_1_0_screw_lid_M3.stl]
2026-07-29 Add interactive assembled and exploded chassis models
2026-07-29 Fix interactive chassis GLB scale and materials
    [generate_project.py]
2026-07-29 Document 50 mm body strap mounting
    [BOM.csv]
2026-07-29 Rotate strap rails for vertical wear
    [BOM.csv, RaptorVR_1_0_case_50mm_strap.stl]
2026-08-01 Use two diagonal screws for enclosure lid
    [RaptorVR_1_0_case_50mm_strap.stl, RaptorVR_1_0_screw_lid_M3.stl]
2026-08-01 Revert "Use two diagonal screws for enclosure lid"
    This reverts commit 8fe383228583845b6d3ff5403472d56455bb9ad3.
    [RaptorVR_1_0_case_50mm_strap.stl, RaptorVR_1_0_screw_lid_M3.stl]
